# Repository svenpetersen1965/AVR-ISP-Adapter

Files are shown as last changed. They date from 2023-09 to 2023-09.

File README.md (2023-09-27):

# AVR-ISP-Adapter
The ISP (in system programming) connector for Atmel µControllers is not compatible for breadboards. This is an adater, which allows to connect a 2x3 pin programmer connector to the projects.

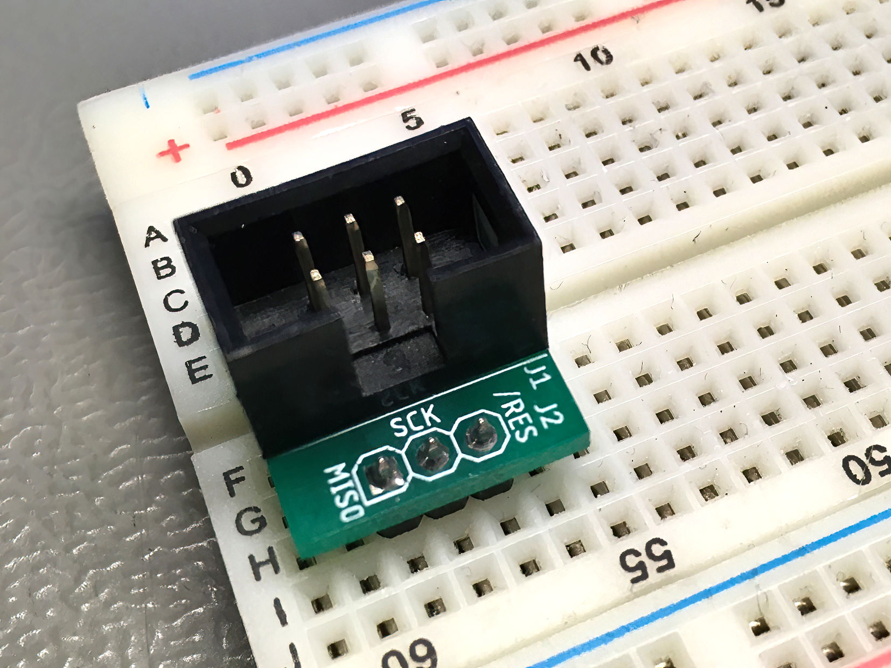
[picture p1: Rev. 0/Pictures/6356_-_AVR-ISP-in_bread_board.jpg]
AVR-ISP Adapter on a breadboard


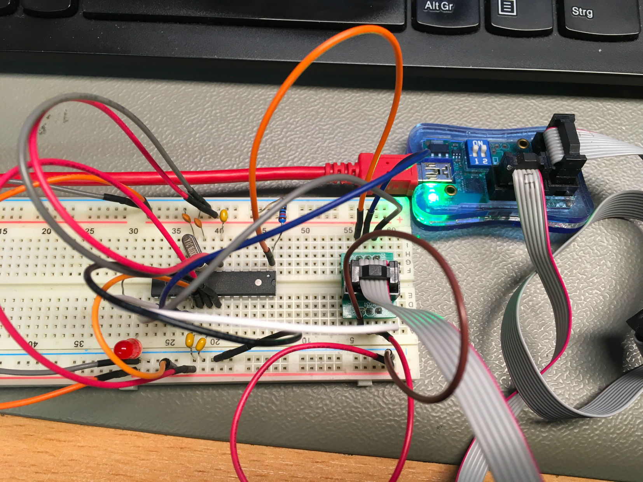
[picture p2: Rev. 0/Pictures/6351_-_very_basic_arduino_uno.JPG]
ATmega328P circuit as a minimum Arduino Uno


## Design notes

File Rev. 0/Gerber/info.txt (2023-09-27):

      
       Board: AVR-ISP
       Rev.:  0
  
       Files:
       ======
  
       All Gerber files are generated in extended gerber format (RS274X)
       *.TOP        : Film top copper
       *.BOT        :  -"- bottom copper
       *.STC        :  -"- top soldermask 
       *.STS        :  -"- bottom soldermask
       *.PLC        :  -"- silk screen top
       *.PLS        :  -"- silk screen bottom
       *.CRC        :  -"- cream top
       *.DK         : Drills plated Through (Excellon)
       *.NDK        : Drills not plated Through (Excellon)
       *.OUT        : Board outline

       Board Size:
       ===========
       Length     :   19.1 mm
       Width      :   15.2 mm
       Thickness  :   1.6 mm
       Material   :   FR 4
       Copper     :   35 um
       Surface    :   HASL
       
       Remarks:
       ========
       width > 6mil
       distane >= 6 mil
       drill >= 6mil

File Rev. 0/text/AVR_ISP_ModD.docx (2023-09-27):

AVR-ISP Bread Board Adapter Rev. 0

Module Description

# Introduction

The purpose of this adapter is connecting the 6 pin AVR In System Programming pin header to a bread board. There is a 6 pin box connector (2x3, 2.54mm) on top and two 3 pin (2.54mm) pin header, 600 mil apart, on the bottom side of the board. This way, it fits into a standard bread board and can be wired up with the processor. The pin header fits the AVR programmers like the Microchip Atmel-ICE, the Diamex USB ISP-Programmer (Atmel AVR) or the cheap (STK500 emulating) programmers, which are available available from AliExpress or ebay etc. for less than 10€.

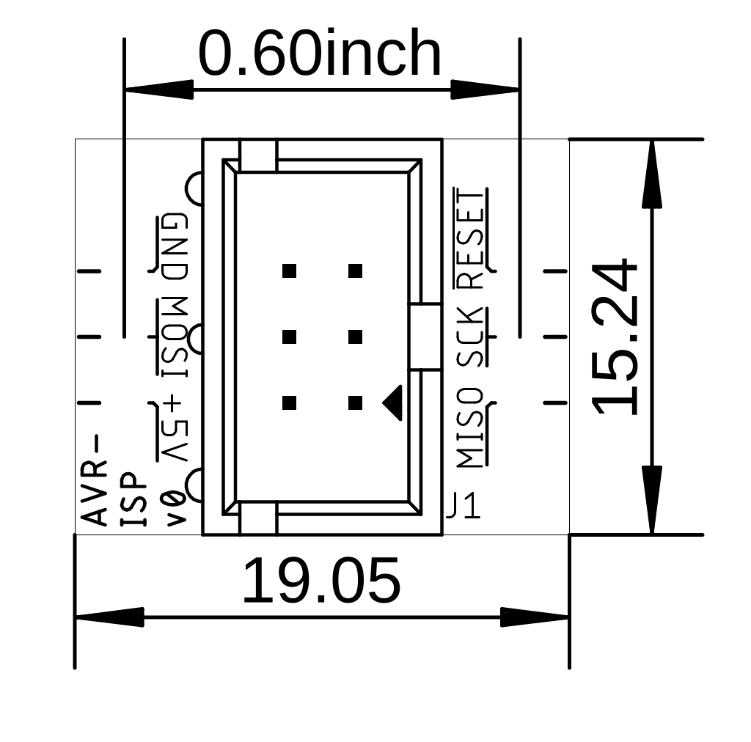
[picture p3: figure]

Figure 1: Dimensions of the PCB

# Connectors

J2 | Signal | J1 | | Signal | J3
1 | MISO | 1 | 2 | +5V | 1
2 | SCK | 3 | 4 | MOSI | 2
3 | | 5 | 6 | GND | 3

J2 and J3 are pin headers placed on the bottom side of the PCB and fit into a bread board

# Revision History

## Rev. 0

- Fully working prototype

AVR_ISP_ModD.docx 25.09.2023 00:39 Drafted by Sven Petersen Page 2 of 2 Doc.-No.: 106-6-01-00

AVR_ISP_ModD.docx 25.09.2023 00:39 Drafted by Sven Petersen Page 1 of 1 Doc.-No.: 000-6-00-00

ENZIANWEG 16 ● 83052 BRUCKMÜHL TEL (08062) 728704 ● FAX (08062) 728705

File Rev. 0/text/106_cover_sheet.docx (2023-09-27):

Project Documentation

AVR-ISP Adapter

Project number: 106

Revision: 0

Date: 04.06.2018

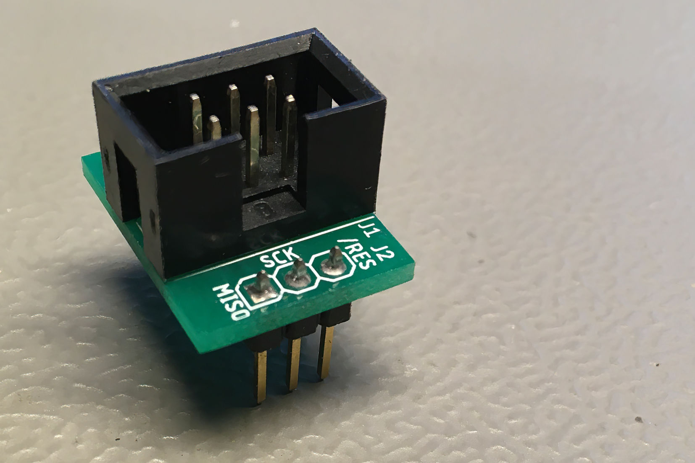
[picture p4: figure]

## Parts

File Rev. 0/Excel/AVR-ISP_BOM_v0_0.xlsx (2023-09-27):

AVR-ISP Adapter Rev. 0
Bill of Material Rev. 0.0
Pos. | Qty | Value | Footprint | Ref.-No. | Comment
1 | 1 | 106-2-01-00 | 2 Layer | PCB Rev. 0 | 2 layer, Cu 35µ, HASL, 19.1mm x 15.2mm, 1.6mm FR4
2 | 1 | WSL 6G | 2X03WV | J1 | box pin header, 2x3pin, 2.54mm pitch
3 | 2 | 1x3 | 1X03 | J2, J3 | pin header 1x3pin, 2.54mm pitch

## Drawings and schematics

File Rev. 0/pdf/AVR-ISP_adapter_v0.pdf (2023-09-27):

# Project Documentation

## AVR-ISP Adapter

## Project number: 106

## Revision: 0

## Date: 04.06.2018

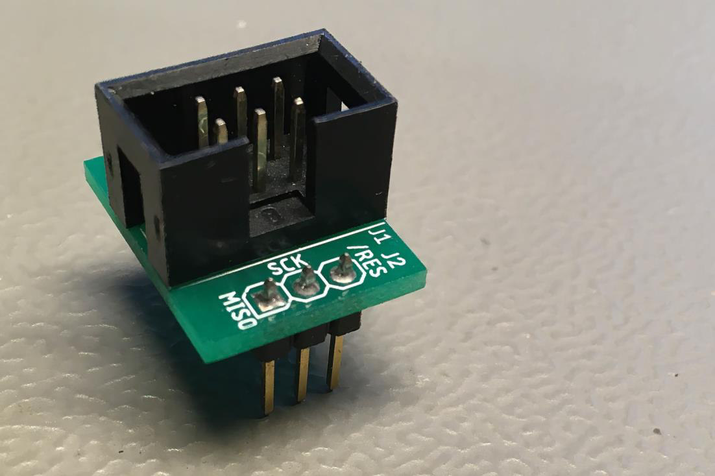
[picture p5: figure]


AVR_ISP_ModD.docx | | 25.09.2023 00:39
Drafted by Sven Petersen | Page 1 of 1 | Doc.-No.: 106-6-01-00

### AVR-ISP Bread Board Adapter Rev. 0

### Module Description

## Introduction

The purpose of this adapter is connecting the 6 pin AVR In System Programming pin header to a bread board. There is a 6 pin box connector (2x3, 2.54mm) on top and two 3 pin (2.54mm) pin header, 600 mil apart, on the bottom side of the board. This way, it fits into a standard bread board and can be wired up with the processor. The pin header fits the AVR programmers like the Microchip Atmel-ICE, the Diamex USB ISP-Programmer (Atmel AVR) or the cheap (STK500 emulating) programmers, which are available available from AliExpress or ebay etc.
for less than 10€.

Figure 1: Dimensions of the PCB

## Connectors

J2 | Signal | J1 | Signal | J3
1 | MISO | 1 | 2 | +5V | 1
2 | SCK | 3 | 4 | MOSI | 2
3 | | 5 | 6 | GND | 3

J2 and J3 are pin headers placed on the bottom side of the PCB and fit into a bread board

## Revision History

### Rev. 0

- Fully working prototype

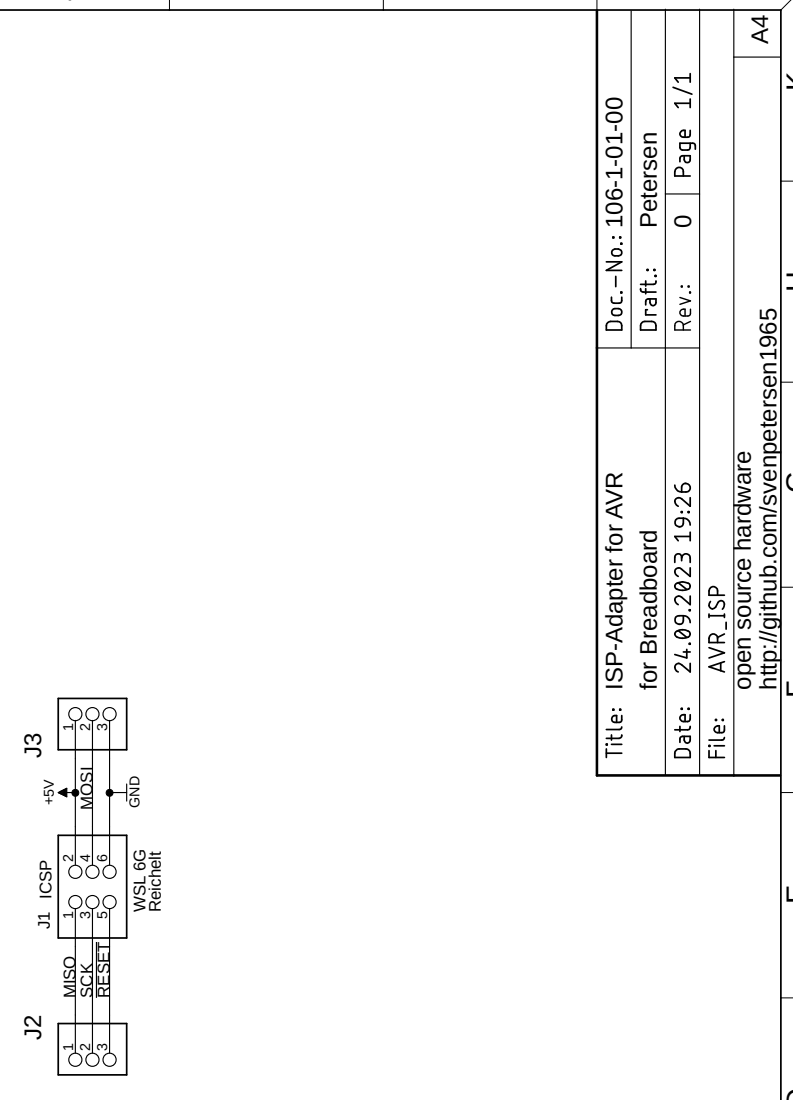
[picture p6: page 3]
WSL 6G Reichelt; GND; ICSP; MISO; SCK; RESET; MOSI

for Breadboard Petersen

http://github.com/svenpetersen1965

open source hardware

ISP-Adapter for AVR

Cu:

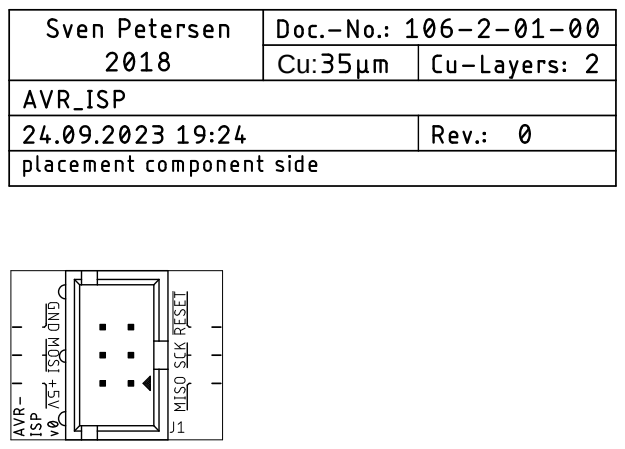
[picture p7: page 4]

Cu:

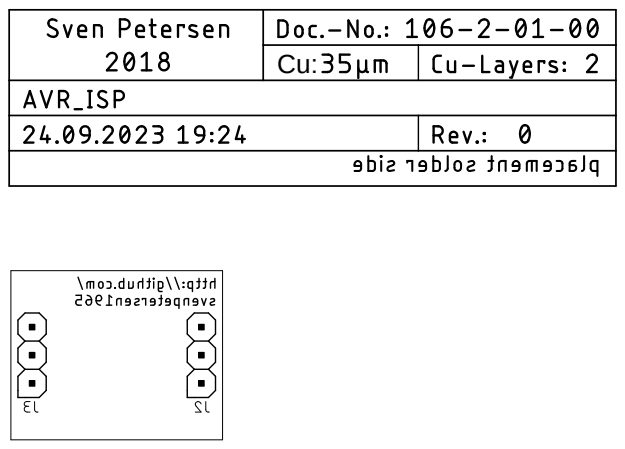
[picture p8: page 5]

Cu:

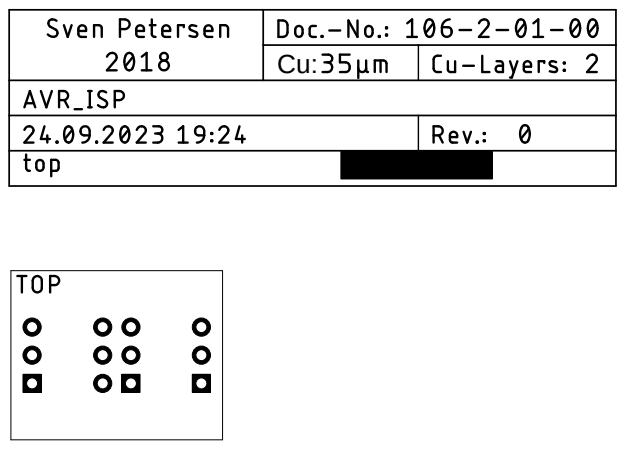
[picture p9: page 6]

Cu:

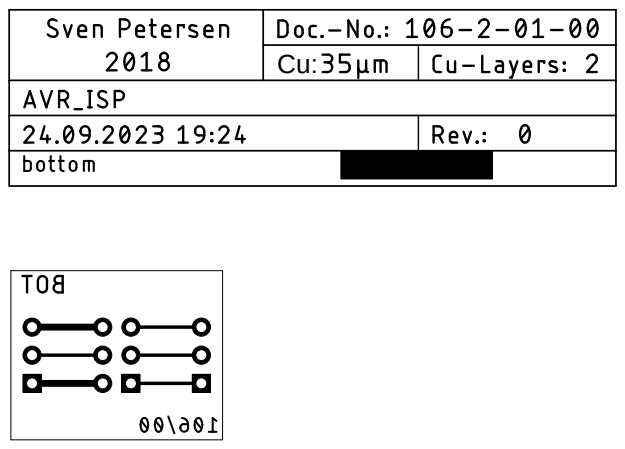
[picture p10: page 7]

Cu:

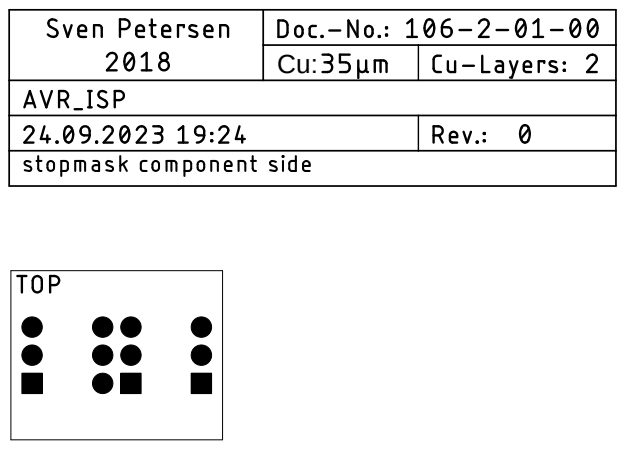
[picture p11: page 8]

Cu:

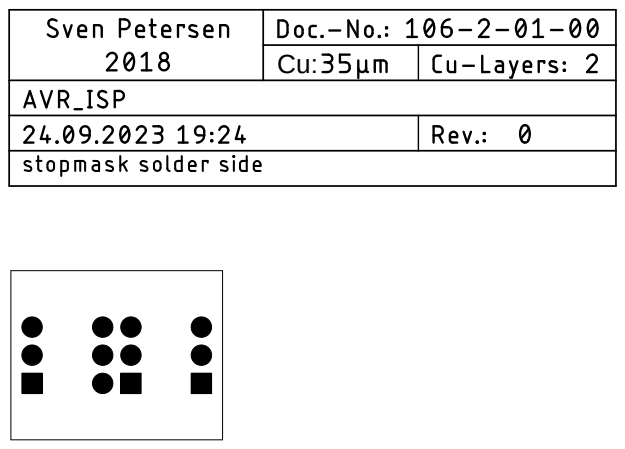
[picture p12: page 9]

## 0.60inch

Cu:

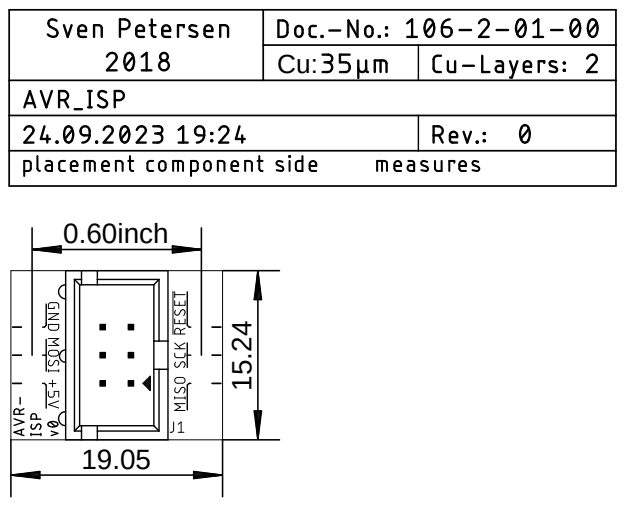
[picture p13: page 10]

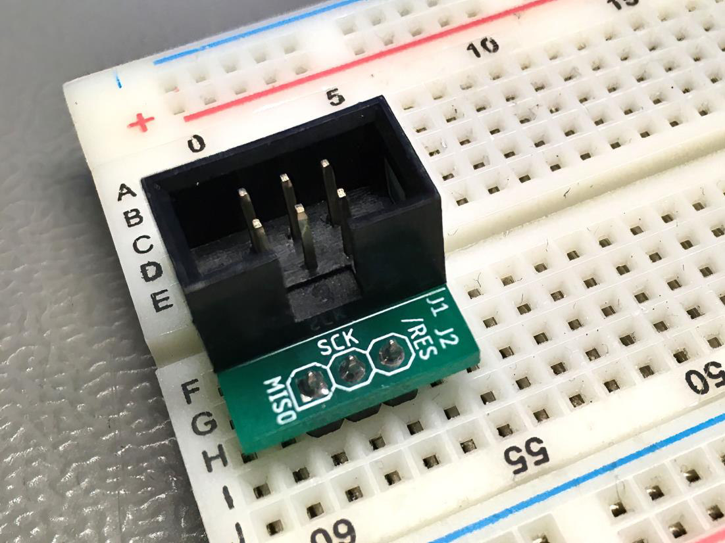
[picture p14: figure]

AVR_ISP_Test.docx | | 25.09.2023 01:02
Drafted by Sven Petersen | Page 1 of 2 | Doc.-No.: 106-6-02-00

### AVR-ISP Bread Board Adapter Rev. 0

### Test Description

## Setup

- AVR-ISP Adapter Rev. 0
- Bread board
- A minimum Arduino UNO circuit wired up on the bread board
- Diamex USB ISP-Programmer (Atmel AVR)
- Arduino IDE (v2.0.4)

## Execution

The circuit as shown in the schematic doc.-no. 106-1-02-00 was wired up on the bread board. The programmer was set to output 5V supply voltage for the connected circuit.

The AVR-ISP adapter was connected to the bread board and wired up with the ATmega328P processor.

The adapter fit into the bread board without a problem.

Figure 1: The AVR-IS adapter connected to a bread board

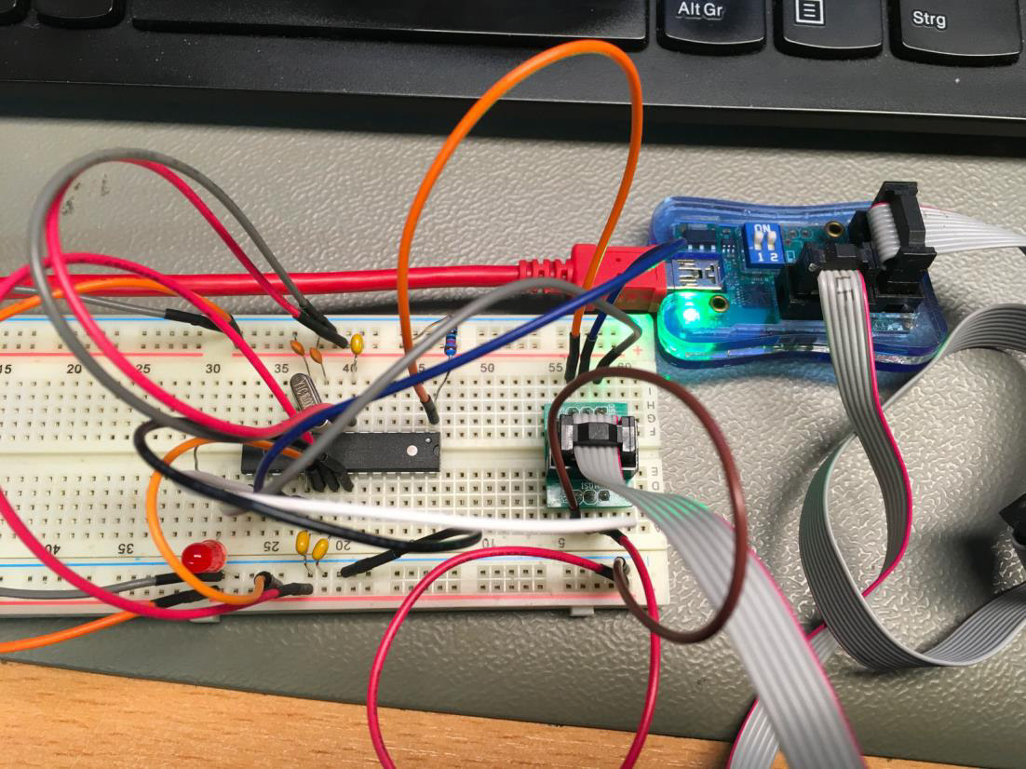
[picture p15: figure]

AVR_ISP_Test.docx | | 25.09.2023 01:02
Drafted by Sven Petersen | Page 2 of 2 | Doc.-No.: 106-6-02-00

Figure 2: The test circuit wired up on the breadboard , programmer connected
The programmer type (STK500) was selected in the Arduino IDE (Tools→…). The port for the programmer was selected. The board type (Arduino Uno) was selected.

Now, the boot loader for Arduino Uno was programmed (Tools→Burn Bootloader). This worked without complains.

Finally, the blink_led13 sketch was programmed via the programmed (Sketch→Upload using programmer). The programming worked out without complaints. The LED started blinking.

## Conclusion

The AVR-ISP adapter Rev. 0 is fully functional.

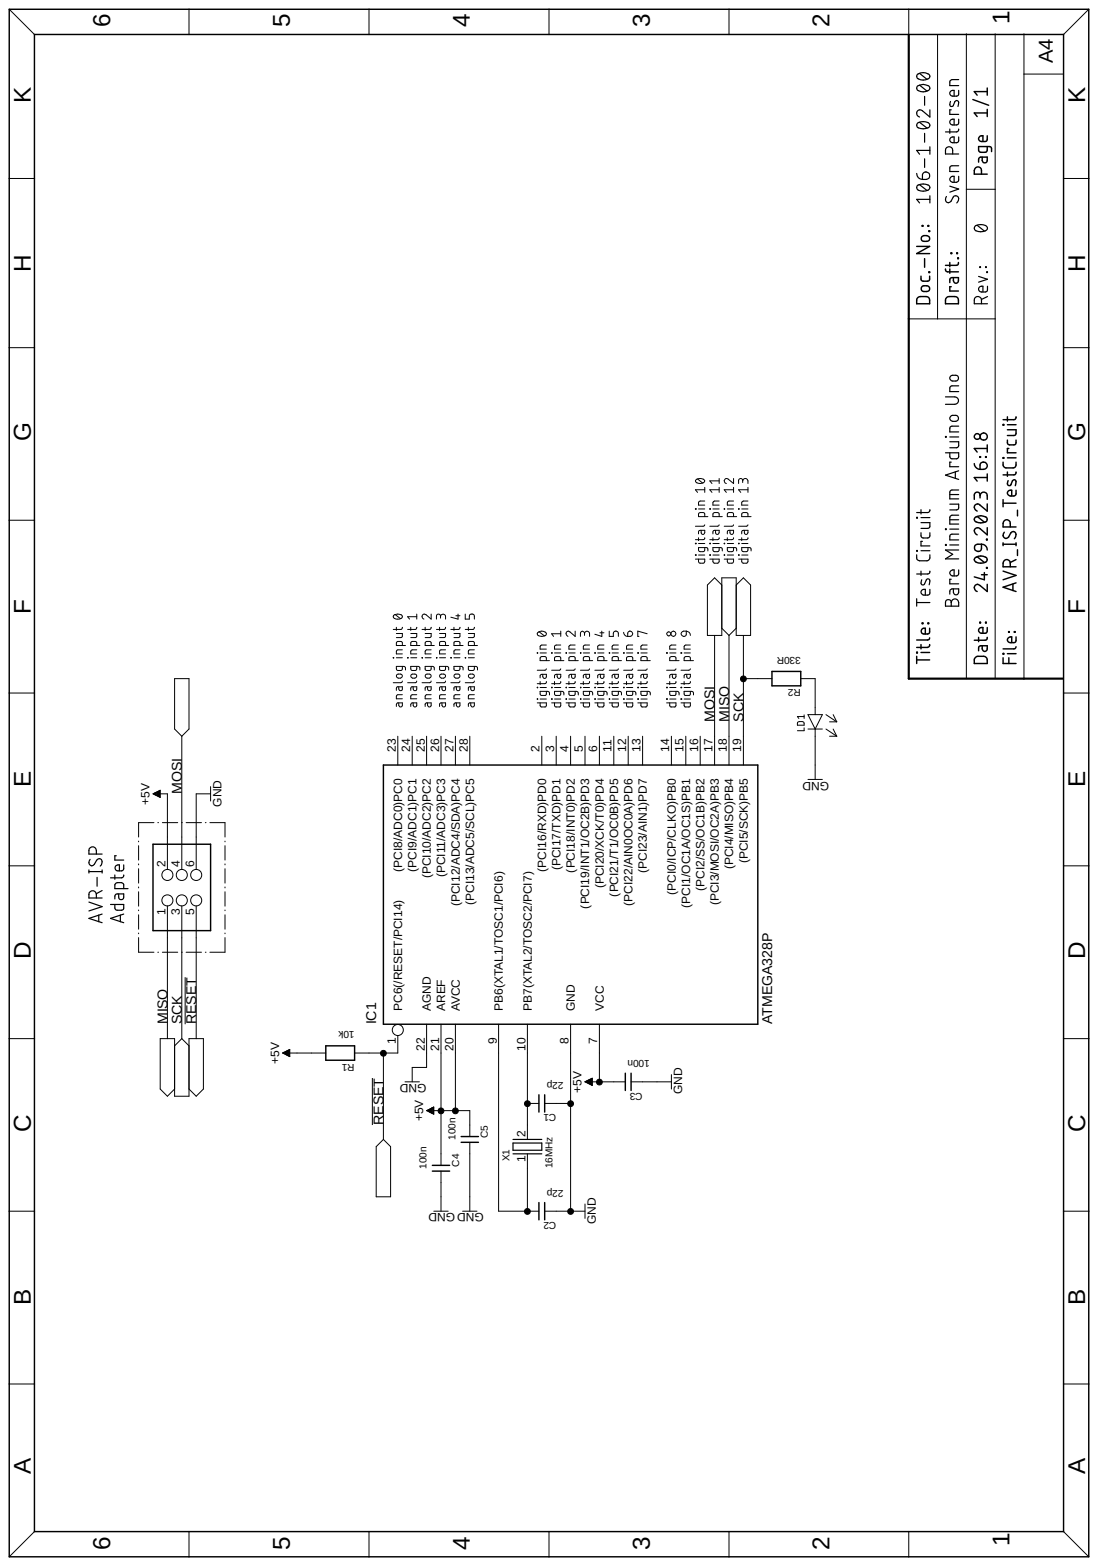
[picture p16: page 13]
GND; ATMEGA328P; 100n GNDGND; (PCI5/SCK)PB5 19; PB7(XTAL2/TOSC2/PCI7) 10; PB6(XTAL1/TOSC1/PCI6) 9; GND 8; VCC 7; AGND 22 AREF 21; AVCC 20; 16MHz; MISO; SCK; RESET; MOSI

(PCI13/ADC5/SCL)PC5 28 (PCI12/ADC4/SDA)PC4 27 (PCI11/ADC3)PC3 26 (PCI10/ADC2)PC2 25 (PCI9/ADC1)PC1 24 (PCI8/ADC0)PC0 23 PC6(/RESET/PCI14) 1

(PCI23/AIN1)PD7 13 (PCI22/AIN0OC0A)PD6 12 (PCI21/T1/OC0B)PD5 11 (PCI20/XCK/T0)PD4 6 (PCI19/INT1/OC2B)PD3 5 (PCI18/INT0)PD2 4 (PCI17/TXD)PD1 3 (PCI16/RXD)PD0 2

(PCI4/MISO)PB4 18 (PCI3/MOSI/OC2A)PB3 17 (PCI2/SS/OC1B)PB2 16 (PCI1/OC1A/OC1S)PB1 15 (PCI0/ICP/CLKO)PB0 14

Pos. Qty Value Footprint Ref.-No. Comment

1 1 106-2-01-00 2 Layer PCB Rev. 0 2 layer, Cu 35µ, HASL, 19.1mm x 15.2mm, 1.6mm FR4

2 1 WSL 6G 2X03WV J1 box pin header, 2x3pin, 2.54mm pitch

3 2 1x3 1X03 J2, J3 pin header 1x3pin, 2.54mm pitch

## AVR-ISP Adapter Rev. 0

## Bill of Material Rev. 0.0

AVR-ISP_BOM_v0_0.xlsx

Drafted by Sven Petersen Page 1 of 1

25.09.2023 01:07
Doc.No.: 106-5-01-00.0

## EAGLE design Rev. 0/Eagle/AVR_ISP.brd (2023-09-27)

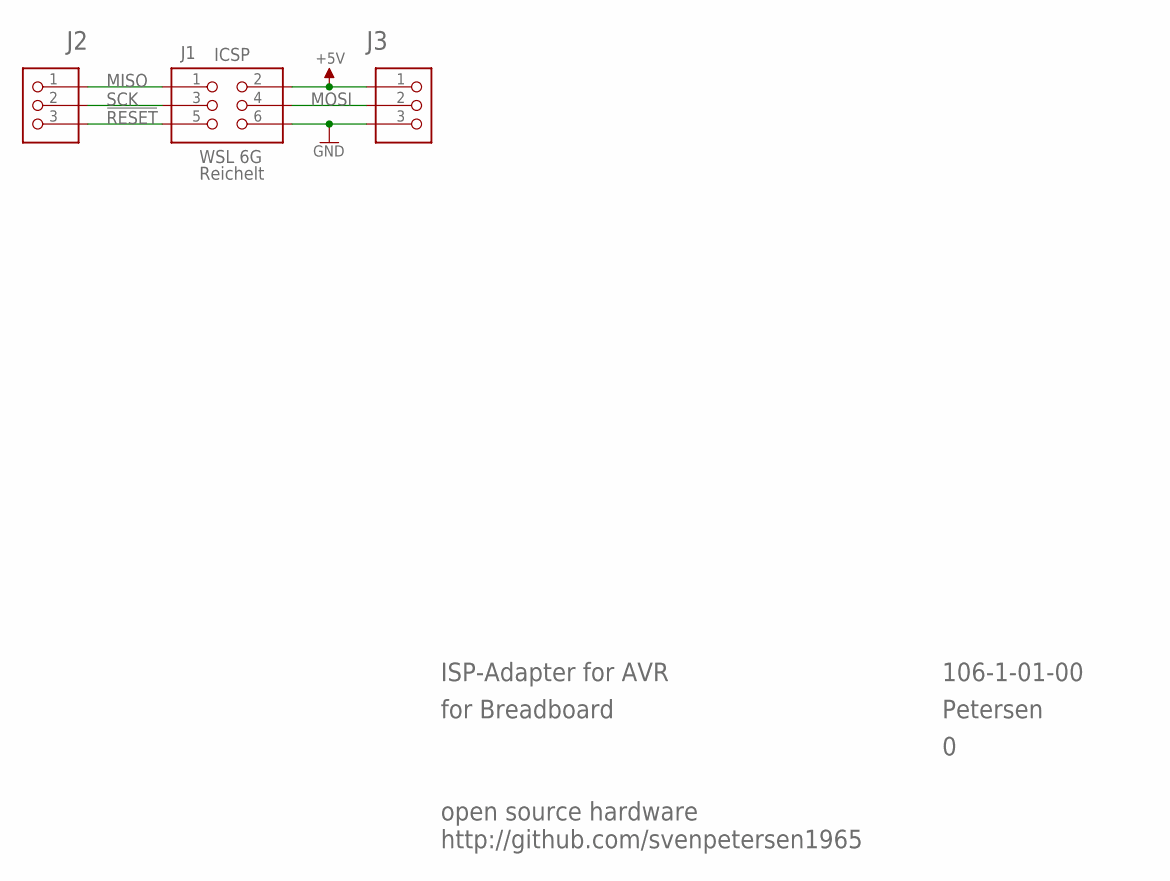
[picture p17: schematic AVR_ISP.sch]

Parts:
J1: WSL 6G; 2X03WV
J2, J3: PINHD-1X3; 1X03

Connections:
!RESET: J1.5, J2.3
+5V: J1.2, J3.1
GND: J1.6, J3.3
MISO: J1.1, J2.1
MOSI: J1.4, J3.2
SCK: J1.3, J2.2

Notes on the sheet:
ICSP
Reichelt
ISP-Adapter for AVR
for Breadboard
Petersen
106-1-01-00
http://github.com/svenpetersen1965
open source hardware

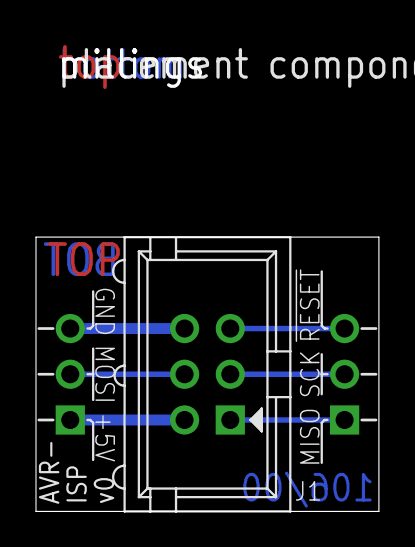
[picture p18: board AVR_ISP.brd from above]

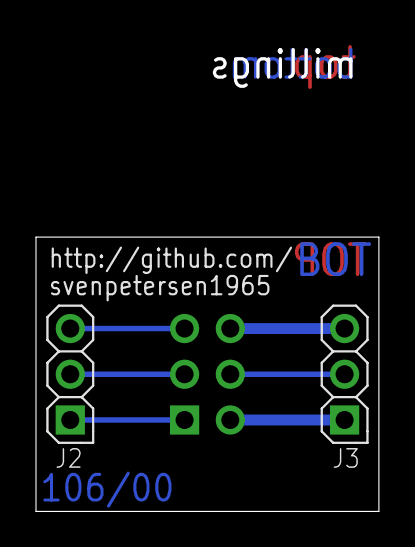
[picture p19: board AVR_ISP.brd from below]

Board: 2 copper layers, 19.1 x 15.2 mm, 5 parts (2 on the bottom side), 6 nets.

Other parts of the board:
U$2: PCB-TITLE/
U$5: 2LAYER
